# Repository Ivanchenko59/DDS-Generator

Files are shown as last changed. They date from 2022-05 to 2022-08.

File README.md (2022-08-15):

# DDS-Generator

## Description
This project is a continuation of the [DDS generator project](https://github.com/Ivanchenko59/AD9833-DDS-Generator), which I did on the STM32F401.
<br/>Please be careful, the project is still under development.

The purpose of this project is to create a small ***educational 
project*** based on the STM32 microcontroller using the HAL library, and also, ***writing a library of the AD9833 chip for experience***.

## About the project

A simple signal generator on the AD9833 chip, which is a DDS generator of different waveform and frequency.
The maximum frequency of the output signal is 12.5 MHz with a reference signal frequency of 25 MHz.
The STM32G030F6P6TR microcontroller is used to control the DDS generator.
A TFT display with a diagonal of 1.8 inches is used to display information.
To conrtor the microcontroller, I used an encoder with hardware filtering on a Schmidt trigger.
As well as two variable resistors for adjusting the amplitude and offset of the output signal.
The device is powered by an external voltage source of 12-24 V.

real

## Demonstration video

#### User interface
Watch the video (https://youtu.be/watch?v=uW_SvFu_fgc)

#### Old video from the previous repo
Watch the video (https://youtu.be/watch?v=vuJpcqhaOHE)

#### Test signal offset and gain
At the moment I can't test this on an oscilloscope, so I'm using an arduino oscilloscope

 Watch the video (https://youtu.be/5M-WV1d51Fs)

## Hardware
PCB

To obtain +12V -12V voltage for the output amplified signal of the generator, 
I used the simplest converter circuit from unipolar to bipolar power, built on a voltage divider with a common point, 
and zero stabilization using an operational amplifier and transistors.

Digital and analog ground are separate to reduce output signal noise.

Amplification and offset of the signal is performed by introducing variable resistors into the feedback loop of the operational amplifier.
According to the principle of operation of the DDS generator and the Nyquist theorem, the maximum frequency of generation is 12.5 MHz for a sinusoidal signal, 
however, such a signal is not suitable for use. 

real_signal

For this, an LC filter of order 7 with a cutoff frequency of 12 MHz was calculated.

frequency_response

We have a signal without distortion and amplitude reduction, up to 5 MHz.

signal_filter

## Software
### CubeMX Connectivity 
cubemx

### SPI Config for ST7735 display

````C++
  hspi1.Instance = SPI1;
  hspi1.Init.Mode = SPI_MODE_MASTER;
  hspi1.Init.Direction = SPI_DIRECTION_2LINES;
  hspi1.Init.DataSize = SPI_DATASIZE_8BIT;
  hspi1.Init.CLKPolarity = SPI_POLARITY_LOW;
  hspi1.Init.CLKPhase = SPI_PHASE_1EDGE;
  hspi1.Init.NSS = SPI_NSS_SOFT;
  hspi1.Init.BaudRatePrescaler = SPI_BAUDRATEPRESCALER_2;
  hspi1.Init.FirstBit = SPI_FIRSTBIT_MSB;
  hspi1.Init.TIMode = SPI_TIMODE_DISABLE;
  hspi1.Init.CRCCalculation = SPI_CRCCALCULATION_DISABLE;
  hspi1.Init.CRCPolynomial = 7;
  hspi1.Init.CRCLength = SPI_CRC_LENGTH_DATASIZE;
  hspi1.Init.NSSPMode = SPI_NSS_PULSE_ENABLE;
````
Redefine SPI PORT if necessary in st7735.h file
````C++
#define ST7735_SPI_PORT   hspi1
````

### SPI Config for AD9833 Gen

````C++
  hspi2.Instance = SPI2;
  hspi2.Init.Mode = SPI_MODE_MASTER;
  hspi2.Init.Direction = SPI_DIRECTION_2LINES;
  hspi2.Init.DataSize = SPI_DATASIZE_8BIT;
  hspi2.Init.CLKPolarity = SPI_POLARITY_HIGH;
  hspi2.Init.CLKPhase = SPI_PHASE_1EDGE;
  hspi2.Init.NSS = SPI_NSS_SOFT;
  hspi2.Init.BaudRatePrescaler = SPI_BAUDRATEPRESCALER_2;
  hspi2.Init.FirstBit = SPI_FIRSTBIT_MSB;
  hspi2.Init.TIMode = SPI_TIMODE_DISABLE;
  hspi2.Init.CRCCalculation = SPI_CRCCALCULATION_DISABLE;
  hspi2.Init.CRCPolynomial = 7;
  hspi2.Init.CRCLength = SPI_CRC_LENGTH_DATASIZE;
  hspi2.Init.NSSPMode = SPI_NSS_PULSE_ENABLE;
````

Redefine SPI PORT if necessary in AD9833.h file
````C++
#define AD9833_SPI_PORT   hspi2
````

### Config Timer for rotary encoder
Enable "Combined Channels" to Encoder Mode in any Timer. The default settings are fine.
<br/>Edit TIM PORT definition in encoder.h
````C++
#define ENC_TIM_PORT      htim3
````
### Lack of memory
I ran into an out-of-memory problem because STM32G030 has only 32KB of FLASH memory. This is quite small when using the HAL library.
<br/>So I used custom sprinf_ implementation cuz original sprintf weight too much.
<br/>I also selected Optimization level to -Os that means optimize for size.
<br/>After that I was able to compile the code.

memory

## Bill of materials
You can find bill of materials in repository.
<br/>Electronic components cost about $15. The PCB's cost $2 for 5 pieces and $10 for shipping.
<br/>Total cost: around $30

## Futures 
- [x] Make PCB board
- [ ] Add oscilloscope measurements
- [ ] Add Sweep mode
- [ ] Add Noise mode

## Disclaimer
The following project is shared "as is", with the sole objective of being useful. 
The creator of the described piece of hardware and its associated software cannot guarantee its correct functioning under any circumstance. 
The author of this project will not be held responsible for any material, personal or economic losses to you or any third parties that may arise from using this design. 
This project will not be used under any circumstances on systems whose responsibility is critical, or from which people's lives depend upon, directly or indirectly.

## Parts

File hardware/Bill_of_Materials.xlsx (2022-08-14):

Comment | Designator | Footprint | LibRef | Quantity | USD | UAH
AD9833 | DA4 | 10-MSOP | AD9833 | 1 | 2.6
AMS1117 | DA1 | SOT-223 | AMS1117 | 1 |  | 4.5
0.1u | C6, C7, C13, C14, C15, C19, C23 | CAP: 0603 | Capacitor | 7
1u 50V | C18 | CAP: 0805 | Capacitor | 1 |  | 1.5
8.2p | C8, C9, C10, C16 | CAP: 0603 | Capacitor | 4
10n | C12, C17 | CAP: 0603 | Capacitor | 2
330p | C21, C24 | CAP: 0805 | Capacitor | 2 |  | 9
510p | C22 | CAP: 0805 | Capacitor | 1 |  | 7
1u 16V | C11 | CAP: TANTAL-A | Capacitor_polar | 1 |  | 2
10u 16V | C1, C20, C25 | CAP: TANTAL-A | Capacitor_polar | 3 |  | 1.5
47u 10V | C3 | CAP: TANTAL-B | Capacitor_polar | 1 |  | 6.5
47u 50V | C2, C4, C5 | CAP: SMD D6.3A6.6H7.7 | Capacitor_polar | 3 |  | 9
ST7735 display | X3 | TFT: 1.8 DISPLAY | Connector Display | 1 | 3
SMA Edge | XW1 | CON: SMA EDGE MOUNT | Connector RF | 1 |  | 30
IDC-10MS | X2 | CON: IDC-10MS | Connector SWD | 1
PJ002 | X1 | CON: PJ002 | DC Jack | 1 |  | 5
EC11 | SW1 | ENC: EC11 | Encoder | 1 | 0.3
1.2uH | L2, L3 | IND: 0805 | Inductor | 2 |  | 9
270nH | L1, L4 | IND: 0805 | Inductor | 2 |  | 8
STM32G030F6P6 | D1 | 20-TSSOP | MCU | 1 | 1
AD8066 | DA3 | 8-SOIC | Op Amp | 1 | 6 |  | replace
LM358 | DA2 | 8-SOIC | Op Amp | 1 |  | 4.5
25 MHz | ZQ1 | OSC: 5070G | Oscillator | 1
10k, 50k | R17, R19 | RES: PTV09A-4015F | Potentiometer | 2 |  | 40
0 | R11, R12, R13, R14 | RES: 0603 | Resistor | 4
1k | R15, R16 | RES: 0805 | Resistor | 2
9.1k | R3, R4, R5, R6, R7, R8, R9, R10 | RES: 0603 | Resistor | 8
10k | R1, R2, R18, R20, R21, R22 | RES: 0805 | Resistor | 6
50 | R23, R26 | RES: 0805 | Resistor | 2
SN74HC14 | DD1 | 14-SOIC | SN74HC14 | 1 |  | 6
BCP56 | VT1 | SOT-223 | Transistor NPN | 1 |  | 7
BCP53 | VT2 | SOT-223 | Transistor PNP | 1 |  | 7
 |  |  |  |  |  |  |  | UAH to USD
 |  |  |  |  | 10.3 | 157.5 | /30 | 5.25
 |  |  |  |  |  |  |  | TOTAL
 |  |  |  |  |  |  |  | 15.55

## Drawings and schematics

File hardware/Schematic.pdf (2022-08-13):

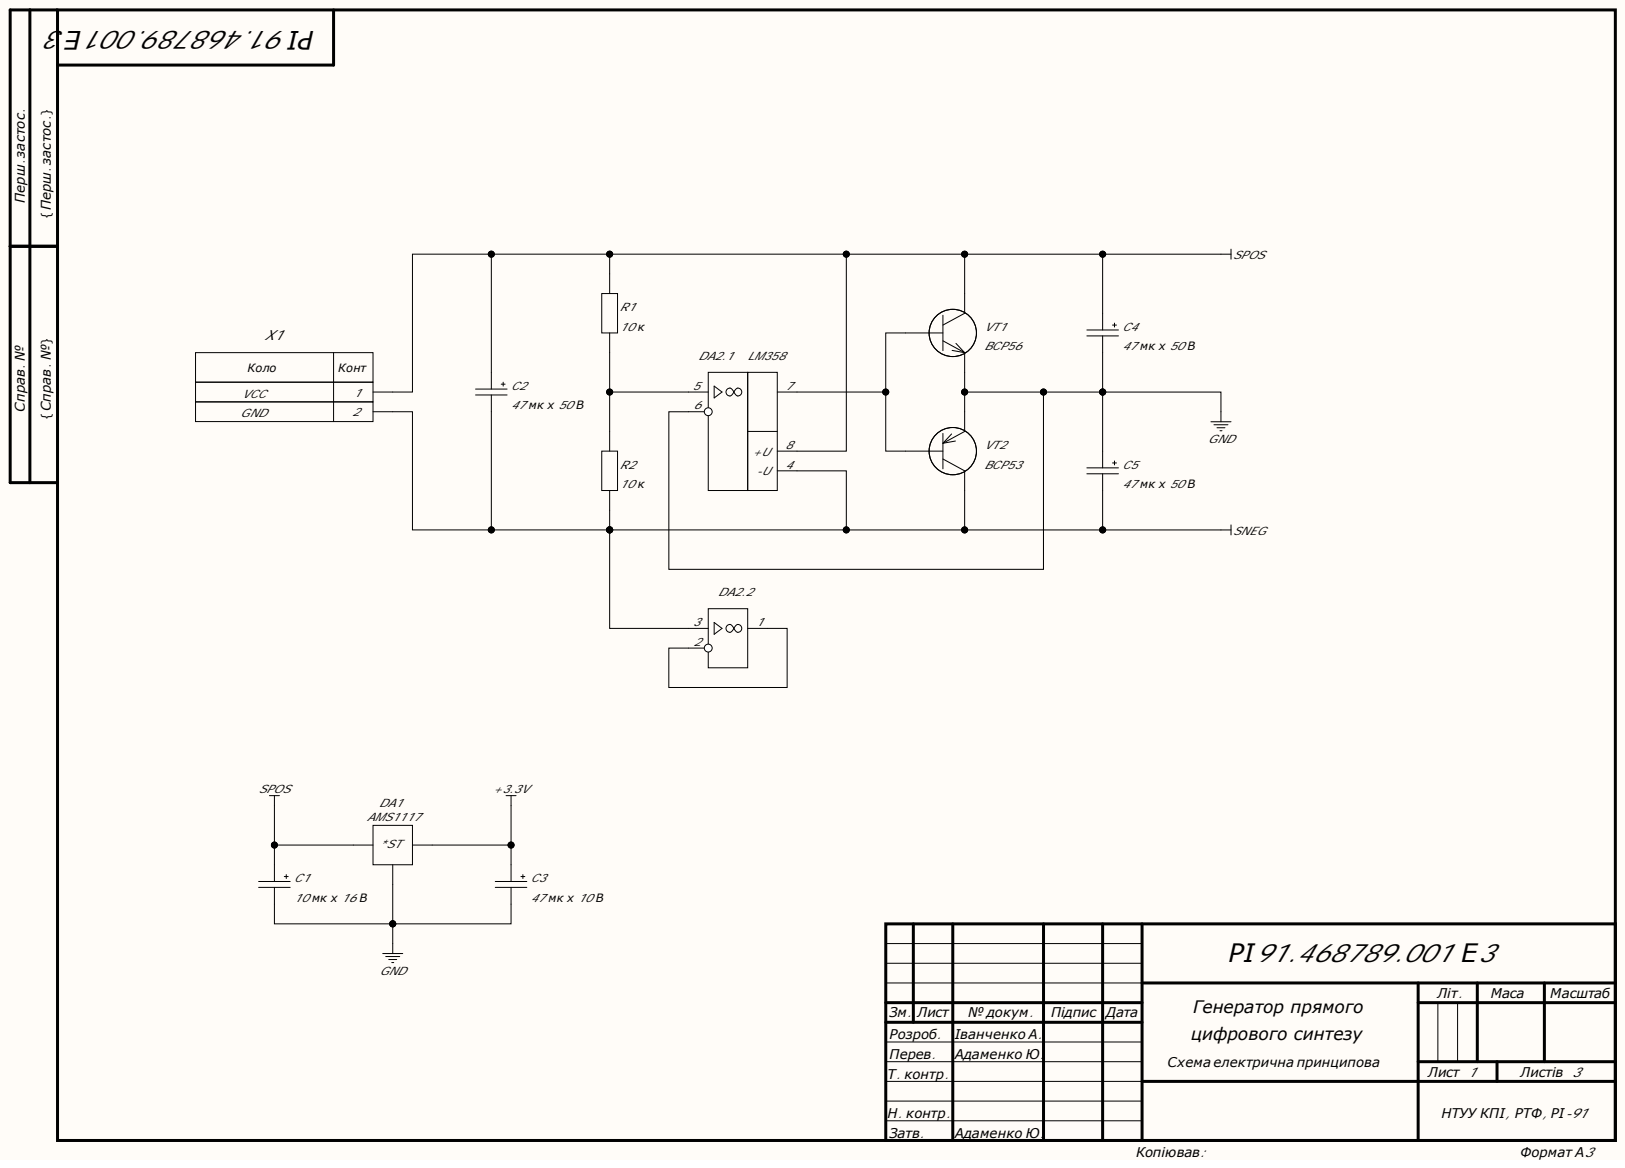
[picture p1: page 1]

GNDКол о | К о н т

Гене р атор пр ямого цифрового синтезу Сх е м а е л е ктрична принципов а | Л і т . | М а са | Мас ш та б

Зм . | Л и с т | № док у м . | П ідпи с | Да та
Роз р о б . | | Іванченк о А .
Пе р е в . | | Адам енк о Ю .
Т. контр . | | | | | Л и с т | Л и с тів

Н. контр .
Затв . | Адам енк о Ю .

НТУУ КП І, РТФ, РІ -

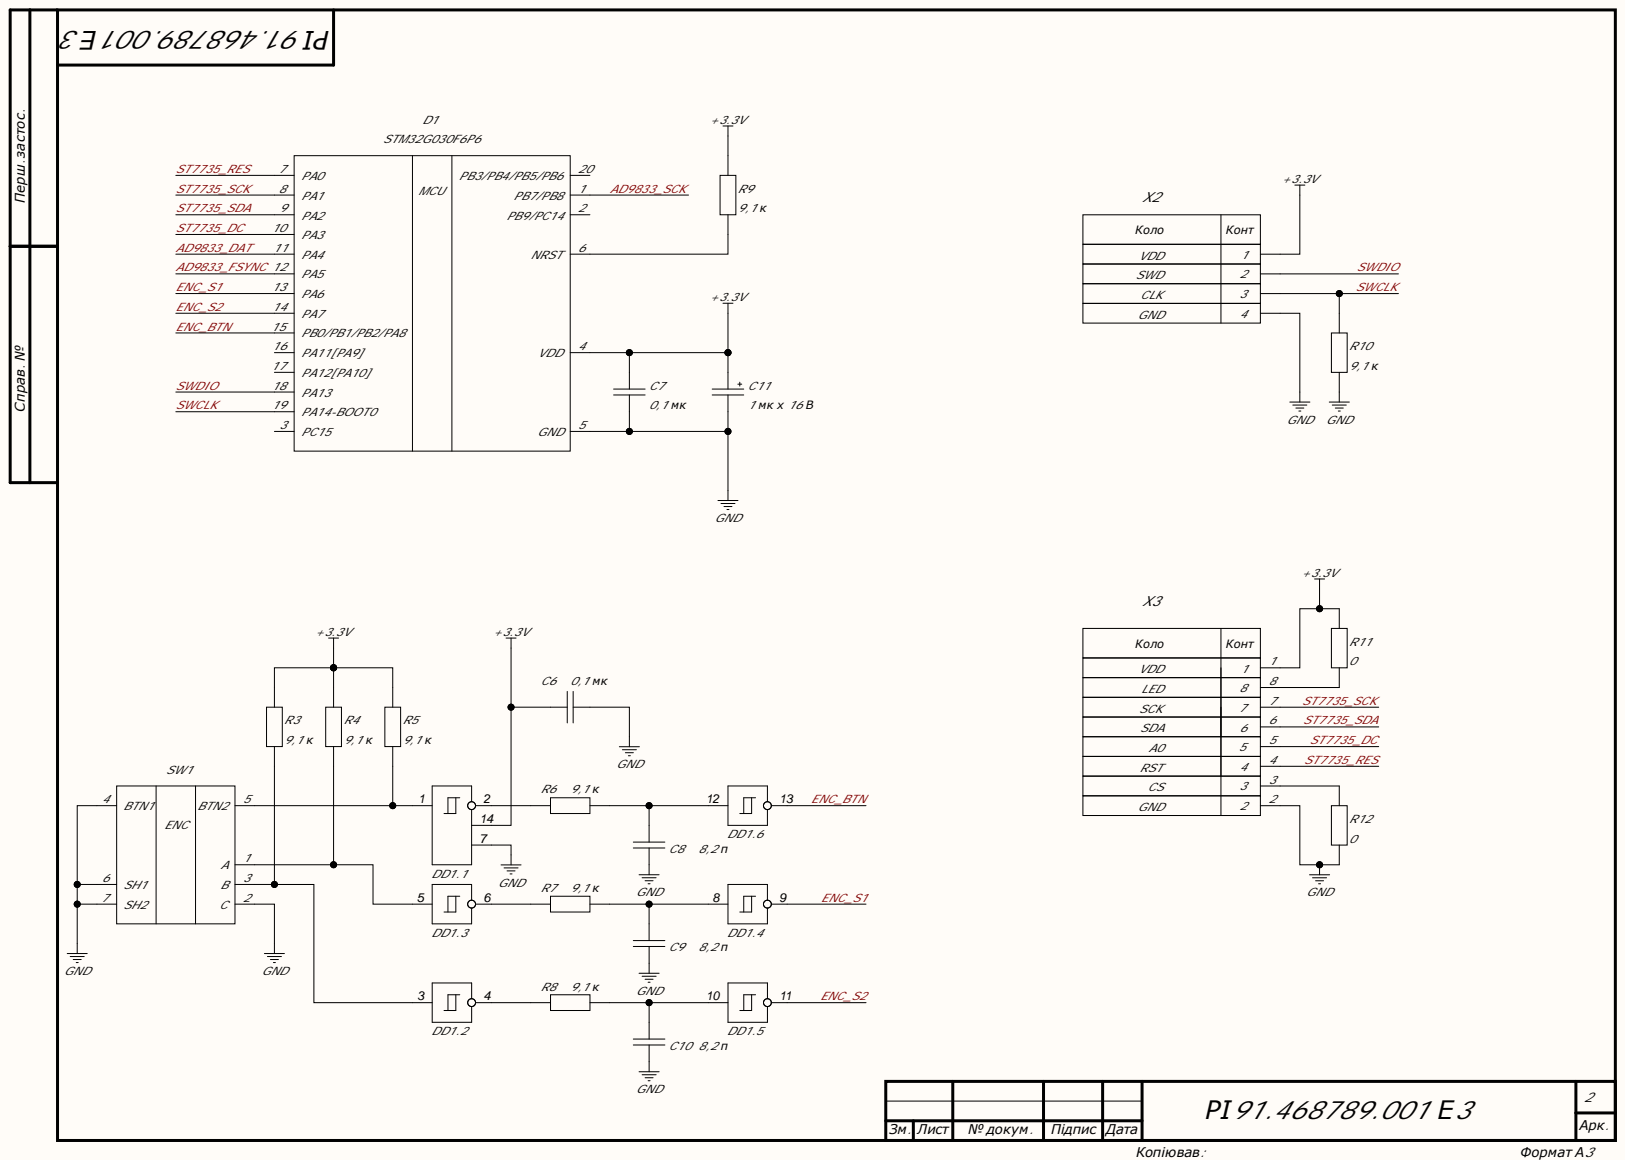
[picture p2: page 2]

GND SWD CLK Коло V D D

LED SCK Коло V D D | 1

S D A | 6
A 0 | 5

GNDCS | 3

Зм . | Л и с т | № док у м . | П ідпи с | Да та

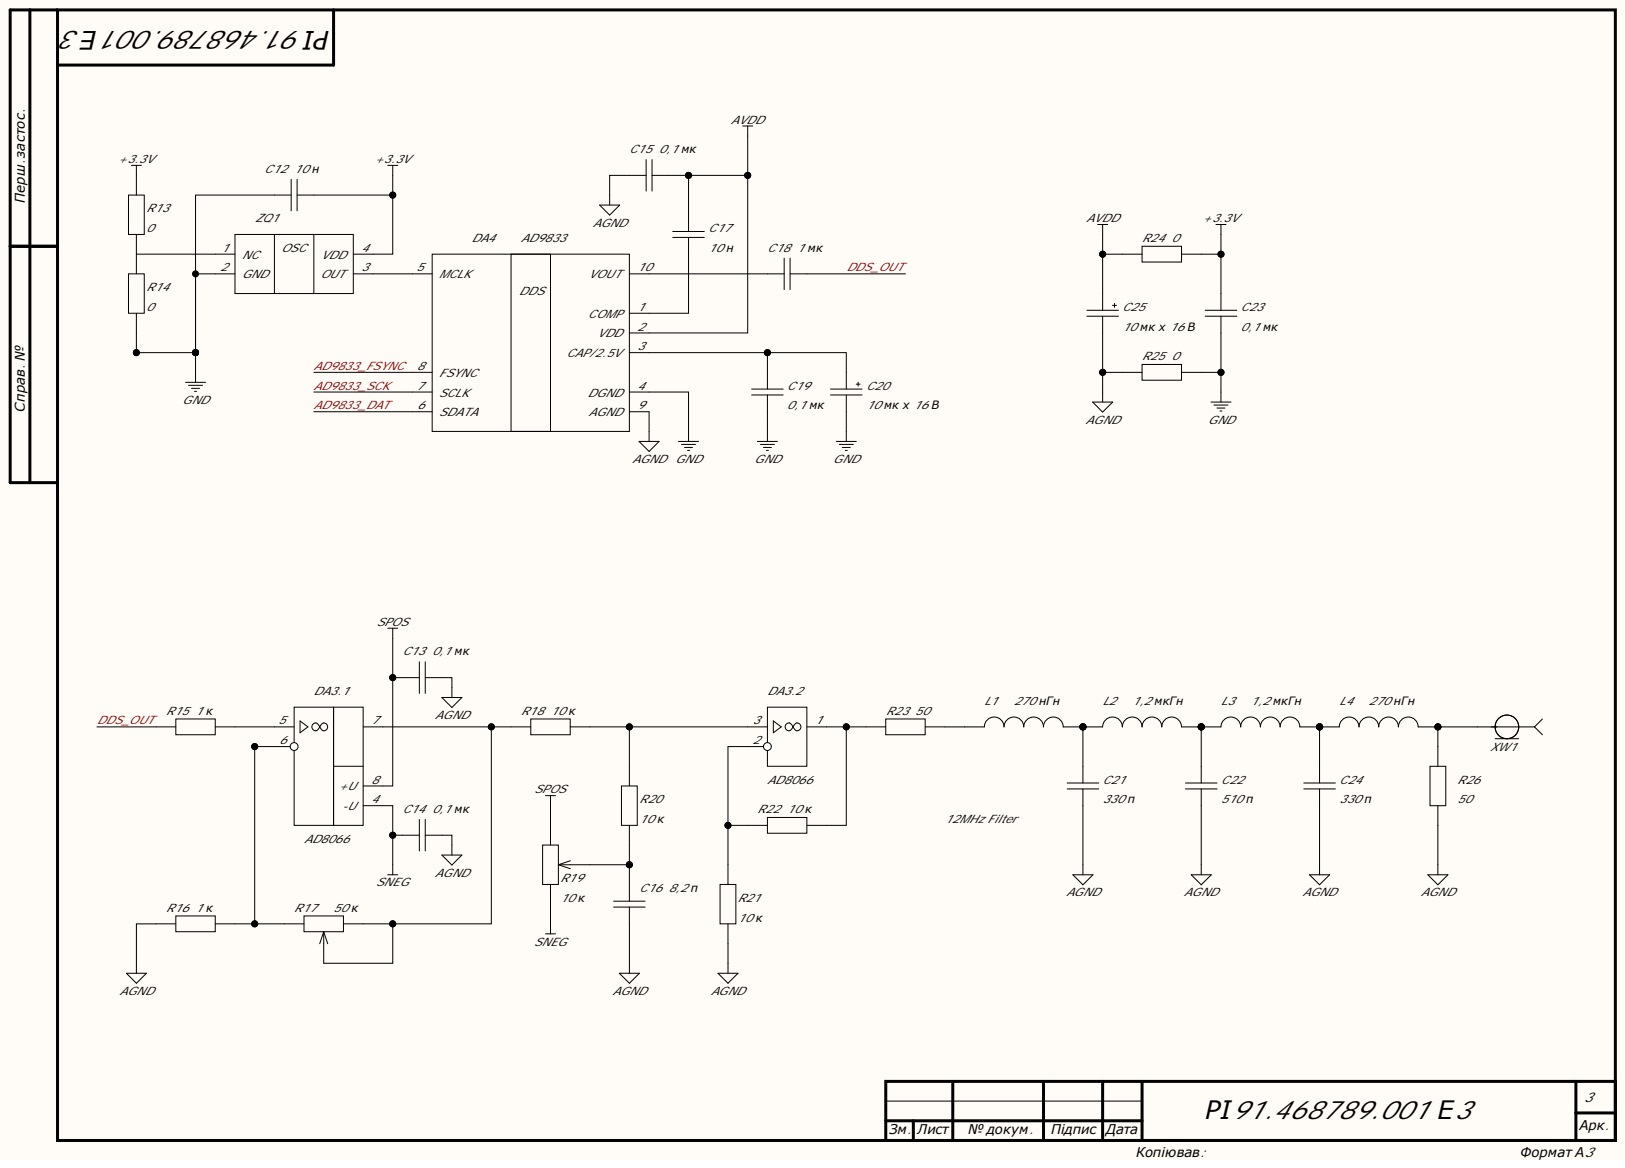
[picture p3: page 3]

Зм. | Лист | № докум. | Підпис | Дата

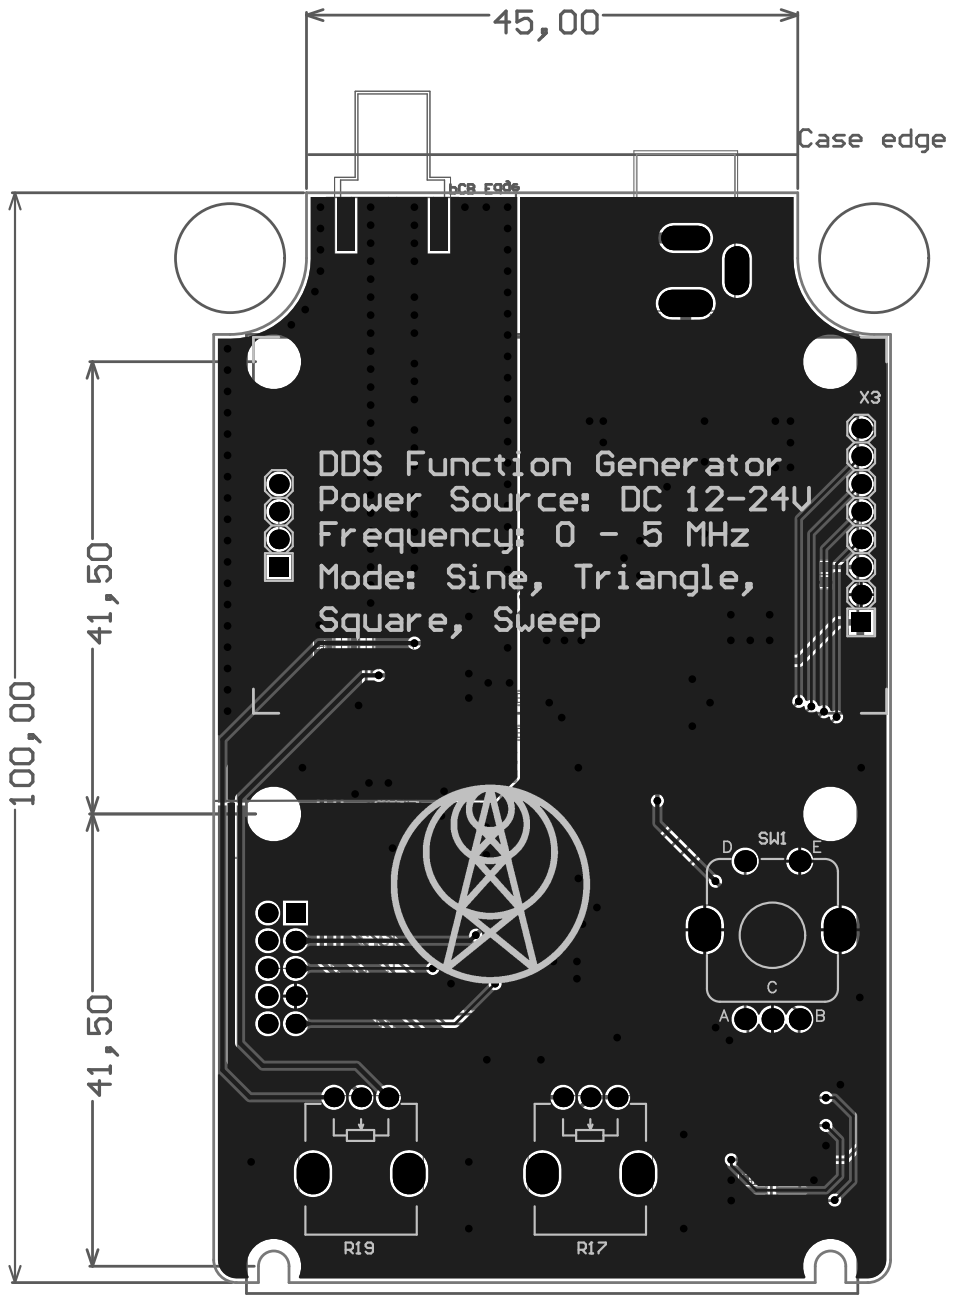
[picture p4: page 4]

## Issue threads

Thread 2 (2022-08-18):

Incorrect work of amplifier

Ivanchenko59, 2022-08-18:
Delete C18 capacitor because high capacitance creates problems for the amplifier

Lagros, 2024-06-30:
According to the scheme P13 P14 0 Ohm. Maybe it’s correct to “not install”?

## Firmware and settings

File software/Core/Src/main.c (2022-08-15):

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
/* Includes ------------------------------------------------------------------*/
#include "main.h"
#include "spi.h"
#include "tim.h"
#include "gpio.h"

/* USER CODE BEGIN Includes */
#include "printf.h"
#include "encoder.h"
#include "AD9833.h"
#include "st7735.h"
#include "fonts.h"
/* USER CODE END Includes */

/* USER CODE BEGIN PTD */
Color_TypeDef text_color = {ST7735_WHITE, ST7735_BLACK, ST7735_BLACK, ST7735_YELLOW};
Selector_TypeDef Menu_Selector = Main_Menu;

/* USER CODE END PTD */


/* USER CODE BEGIN PV */
uint32_t curr_time = 0;
uint32_t freq = 100;
int8_t edit_pos = 2;
int8_t waveform_select = 2;
int8_t encoder_status;
uint8_t button_status;
uint16_t MHz, kHz, Hz;
char Str_Buffer[10];
uint8_t short_press_flag = 0;
uint8_t hide_apply_flag = 0;
/* USER CODE END PV */

void SystemClock_Config(void);
/**
  * @brief  The application entry point.
  * @retval int
  */
int main(void)
{
  /* MCU Configuration--------------------------------------------------------*/

  /* Reset of all peripherals, Initializes the Flash interface and the Systick. */
  HAL_Init();

  /* Configure the system clock */
  SystemClock_Config();

  /* Initialize all configured peripherals */
  MX_GPIO_Init();
  MX_SPI1_Init();
  MX_SPI2_Init();
  MX_TIM3_Init();
  /* USER CODE BEGIN 2 */
  ST7735_Init();
  Encoder_Init();
  AD9833_Init(wave_sine, freq, 0);
  /* USER CODE END 2 */

  /* Infinite loop */
  /* USER CODE BEGIN WHILE */

  ST7735_FillScreen(ST7735_BLACK);
  ST7735_FillRectangle(25, 70, 12, 2, ST7735_DARKGREY);
  ST7735_FillRectangle(49, 70, 35, 2, ST7735_DARKGREY);
  ST7735_FillRectangle(97, 70, 35, 2, ST7735_DARKGREY);
  ST7735_WriteString(10, 4, "AD9833 DDS GENERATOR", Font_7x10, ST7735_DARKGREY, ST7735_BLACK);
  ST7735_WriteString(21, 75, "MHz  kHz    Hz", Font_7x10, ST7735_DARKGREY, ST7735_BLACK);
  SineIcon(18, 92, ST7735_YELLOW);
  SquareIcon(63, 92, ST7735_LIGHTGREY);
  TriangleIcon(108, 92, ST7735_LIGHTGREY);

  MHz = freq / 1000000;
  kHz = freq / 1000 % 1000;
  Hz = freq % 1000;
  sprintf_(Str_Buffer, "%1d,%03d,%03d", MHz, kHz, Hz);

  while (1)
  {
	  //TODO: Stop counting Encoder Tim because its influences to position
	  button_status = Button_Get_Status();

	  switch(Menu_Selector) {
		  case Main_Menu:
			  ST7735_WriteString(25, 50, Str_Buffer, Font_12x18, ST7735_WHITE, ST7735_BLACK);
			  if((HAL_GetTick() - curr_time > APPLY_SHOW_TIME) && hide_apply_flag) {
				  ST7735_WriteString(30, 30, "               ", Font_7x10, ST7735_DARKGREY, ST7735_BLACK);
				  hide_apply_flag = 0;
			  }
			  if (button_status == Short_Press) Menu_Selector = Change_Frequency;
			  if (button_status == Long_Press) Menu_Selector = Change_Wave_Form;
			  break;

		  case Change_Wave_Form:
			  ST7735_WriteString(30, 30, "Change Waveform", Font_7x10, ST7735_DARKGREY, ST7735_BLACK);
			  ST7735_WriteString(25, 50, Str_Buffer, Font_12x18, ST7735_WHITE, ST7735_BLACK);
			  Change_Position(&waveform_select, MAX_WAVEFORM);
			  if (waveform_select == wave_sine) {
				  SineIcon(18, 92, ST7735_YELLOW);
				  SquareIcon(63, 92, ST7735_LIGHTGREY);
				  TriangleIcon(108, 92, ST7735_LIGHTGREY);
			  }
			  else if (waveform_select == wave_square) {
				  SineIcon(18, 92, ST7735_LIGHTGREY);
				  SquareIcon(63, 92, ST7735_YELLOW);
				  TriangleIcon(108, 92, ST7735_LIGHTGREY);
			  }
			  else if (waveform_select == wave_triangle) {
				  SineIcon(18, 92, ST7735_LIGHTGREY);
				  SquareIcon(63, 92, ST7735_LIGHTGREY);
				  TriangleIcon(108, 92, ST7735_YELLOW);
			  }

			  if (button_status == Short_Press) {
				  AD9833_SetWaveform(waveform_select);
				  Menu_Selector = Main_Menu;
				  ST7735_WriteString(30, 30, "    Apply!     ", Font_7x10, ST7735_DARKGREY, ST7735_BLACK);
				  hide_apply_flag = 1;
				  curr_time = HAL_GetTick();
			  }
			  if (button_status == Long_Press) {
//				  Menu_Selector = Main_Menu;
//				  or something else?
			  }
			  break;

		  case Change_Frequency:
			  ST7735_WriteString(30, 30, "Edit Frequency ", Font_7x10, ST7735_DARKGREY, ST7735_BLACK);
			  (short_press_flag) ? Edit_Frequency(edit_pos, &freq) : Change_Position(&edit_pos, MAX_DIGITS);

			  MHz = freq / 1000000;
			  kHz = freq / 1000 % 1000;
			  Hz = freq % 1000;

			  sprintf_(Str_Buffer, "%1d,%03d,%03d", MHz, kHz, Hz);
			  ST7735_WriteStringWithSelect(25, 50, Str_Buffer, Font_12x18, edit_pos, text_color);

			  if (button_status == Short_Press) {
				  short_press_flag = !short_press_flag;
			  }
			  if (button_status == Long_Press) {
				  AD9833_SetFrequency(freq);
				  ST7735_WriteString(30, 30, "    Apply!    ", Font_7x10, ST7735_DARKGREY, ST7735_BLACK);
				  hide_apply_flag = 1;
				  curr_time = HAL_GetTick();
				  Menu_Selector = Main_Menu;
				  short_press_flag = 0;
			  }
			  break;

		  case Sweep_Mode:
			  //TODO: Sweep

			  break;

		  default:
			  break;
	  }

    /* USER CODE END WHILE */

    /* USER CODE BEGIN 3 */
  }
  /* USER CODE END 3 */
}

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
/* USER CODE BEGIN 4 */
void Edit_Frequency(int8_t position, uint32_t* const p_freq)
{
	uint32_t pos_to_Hz = int_pow(10, position);
	uint32_t edit_value = *p_freq / pos_to_Hz;

	switch(Encoder_Get_Status()) {
		  case Incremented:
			  edit_value++;
			  break;
		  case Decremented:
			  if(edit_value > 0)
				  edit_value--;
			  break;
		  case Neutral:
			  break;
	  }

	uint32_t edited_freq = edit_value * pos_to_Hz + *p_freq % pos_to_Hz;

	if (edited_freq <= MAX_FREQ_VALUE)
		*p_freq = edited_freq;
}

void Change_Position(int8_t* const edit_pos, uint8_t MAX_POS)
{
	switch(Encoder_Get_Status()) {
		case Incremented:
			(*edit_pos)--;
			if (*edit_pos < 0) *edit_pos = MAX_POS - 1;
			break;
		case Decremented:
			(*edit_pos)++;
			if (*edit_pos >= MAX_POS) *edit_pos = 0;
			break;
		case Neutral:
			break;
	}
}

uint32_t int_pow(uint32_t base, uint8_t exp)
{
    uint32_t result = 1;
    while (exp) {
        if (exp % 2)
           result *= base;
        exp /= 2;
        base *= base;
    }
    return result;
}
/* USER CODE END 4 */
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


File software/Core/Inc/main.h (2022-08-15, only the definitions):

#define AD9833_SCK_Pin GPIO_PIN_8
#define AD9833_SCK_GPIO_Port GPIOB
#define ST7735_RES_Pin GPIO_PIN_0
#define ST7735_RES_GPIO_Port GPIOA
#define ST7735_SCK_Pin GPIO_PIN_1
#define ST7735_SCK_GPIO_Port GPIOA
#define ST7735_SDA_Pin GPIO_PIN_2
#define ST7735_SDA_GPIO_Port GPIOA
#define ST7735_DC_Pin GPIO_PIN_3
#define ST7735_DC_GPIO_Port GPIOA
#define AD9833_DAT_Pin GPIO_PIN_4
#define AD9833_DAT_GPIO_Port GPIOA
#define AD9833_FSYNC_Pin GPIO_PIN_5
#define AD9833_FSYNC_GPIO_Port GPIOA
#define ENC_S1_Pin GPIO_PIN_6
#define ENC_S1_GPIO_Port GPIOA
#define ENC_S2_Pin GPIO_PIN_7
#define ENC_S2_GPIO_Port GPIOA
#define ENC_BTN_Pin GPIO_PIN_0
#define ENC_BTN_GPIO_Port GPIOB
#define MAX_FREQ_VALUE 5000000
#define MAX_DIGITS 7
#define MAX_WAVEFORM 3
#define APPLY_SHOW_TIME 1000

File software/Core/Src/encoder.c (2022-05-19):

/*
 * @file encoder.c
 * @brief Functions for the rotary encoder
 *
 * This contains functions for working with
 * rotary encoder and push button.
 *
 * @author Andrii Ivanchenko
 */

#include "encoder.h"
#include "tim.h"

static int16_t new_count = 0;
static int16_t prev_count = 0;

bit_fied_TypeDef btn = {0, 0, 0};

uint32_t btn_time = 0;

/*
 * @brief Starts the TIM Encoder Interface
 */
void Encoder_Init(void)
{
	HAL_TIM_Encoder_Start(&ENC_TIM_PORT, TIM_CHANNEL_ALL);
}

/*
 * @brief Read Timer Counter Register value
 * @retval Value of the timer counter register (TIM1_CNT) divided by 2
 */
uint16_t Encoder_Read(void)
{
	int16_t val = __HAL_TIM_GET_COUNTER(&ENC_TIM_PORT);
	return val >> 1;
}

/*
 * @brief Read the current state of the encoder
 * @retval Current encoder status
 */
Encoder_Status Encoder_Get_Status(void)
{
	new_count = Encoder_Read();
	if (new_count != prev_count) {
		if (new_count > prev_count) {
			prev_count = new_count;
			return Incremented;
		}
		else if (new_count < prev_count){
			prev_count = new_count;
			return Decremented;
		}
	}
	return Neutral;
}

/*
 * @brief Read and recognizes long and short presses encoder button
 * @retval Current encoder button status
 */
Button_Status Button_Get_Status(void)
{
	btn.state = !HAL_GPIO_ReadPin(ENC_BTN_GPIO_Port, ENC_BTN_Pin);

	if (btn.state && !btn.short_state && ((HAL_GetTick() - btn_time) > BUTTON_SHORT_PRESS_DELAY)) {
		btn.short_state = 1;
		btn.long_state = 0;
		btn_time = HAL_GetTick();
	}
	else if (btn.state && !btn.long_state && (HAL_GetTick() - btn_time) > BUTTON_LONG_PRESS_DELAY) {
		btn.long_state = 1;
		return Long_Press;
	}
	else if (!btn.state && btn.short_state && (HAL_GetTick() - btn_time) > BUTTON_SHORT_PRESS_DELAY) {
		btn.short_state = 0;
		btn_time = HAL_GetTick();
		if(!btn.long_state) {
			return Short_Press;
		}
	}
	return False_Press;
}

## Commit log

2022-08-13 added hardware project
    [1_Power.SchDoc, 2_MCU.SchDoc, 3_RF.SchDoc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]
2022-08-14 added bill of materials
    [Bill_of_Materials.xlsx]
2022-08-30 deleted unused footprints
2022-08-30 Fixed #1; added gerber files
    [1_Power.SchDoc, 2_MCU.SchDoc, 3_RF.SchDoc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]

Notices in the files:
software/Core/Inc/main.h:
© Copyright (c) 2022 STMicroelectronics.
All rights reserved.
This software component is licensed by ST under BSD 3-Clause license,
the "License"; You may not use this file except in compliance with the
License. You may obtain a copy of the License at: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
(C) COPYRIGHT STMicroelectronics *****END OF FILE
